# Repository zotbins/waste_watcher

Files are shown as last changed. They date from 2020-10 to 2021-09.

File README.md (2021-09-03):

# Introduction
I wanted a way to keep track of how much waste I was generating just to be more environmentally conscious. So I created this project as an automated way to help keep track of waste accumulation through fullness measurements while also taking pictures of the objects thrown away.

feature photo

# ZotBins Community Edition

This is the first step of a multi-part project of creating a smart waste ecosystem called [ZotBins](https://zotbins.github.io), which is already deployed at UCI. Currently, I am helping to further expand the concept of ZotBins where any city, business, university, classroom, or home could implement a smart waste system. This open-source version ZotBins is called  ZotBins Community Edition (ZBCE). To learn more about this initiative please visit the [ZotBins Community Edition Blog](https://zotbins.github.io/zbceblog/about/)

# Quick Start
Please follow the appropriate build guide for the waste watcher version of your choosing.
- [Waste Watcher Guide](https://github.com/zotbins/waste_watcher/blob/release-v1/guide/guide.md)
    - Measures bin fullness and collects waste images
    - Saves data and images to HTTP server
    - Syncs with NTP Client to generate UTC datetime stamps

# Contributing

Here are some following ways you can contribute:
- For this specific repository feel free to submit any issues regarding bugs. This will really help other users who may be interested in building this project and also help me create a debugging guide for the community.
- Join our [Discord](https://discord.gg/mGKVVpxTPr) server and contribute to our growing community
- Submit bugs by opening an issue on our [Github](https://github.com/zotbins). Please make sure that bugs are reported in detail and is reproducible.
- Write some documentation for a repository and we can add it to our GitHub Wiki Page
- Look for open issues on our repositories
- Suggest new features in our Discord Server
- Contribute to our crowd-sourcing projects. Occasionally, we will have certain projects that require crowd-sourced data, and would love people to help.
- Submit user feedback through feedback forms or polls in our Discord community
- Lookout for more requests for help on our Discord server

Overall, if you contribute to our project, we will feature your username on respective GitHub repositories. We really appreciate the help. For more ideas about how you can contribute to open source projects in general, feel free to take a look GitHub's [Open Source Guides](https://opensource.guide/how-to-contribute/).

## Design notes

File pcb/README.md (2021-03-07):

I also shared the project on Osh Park where you can purchase the PCB from this [link](https://oshpark.com/shared_projects/k4JhZQq0). All gerber files are also included in this folder if you wish to send to a different manufacturer or fabricate it yourself.

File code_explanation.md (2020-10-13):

# Code Explanation

First, I would really like to thank and acknowledge [Random Nerd Tutorials](https://randomnerdtutorials.com/) for giving the resources and tutorials needed to help me develop this script. They make all their tutorials free and also do their best to help out their community and give so many valuble resources for makers. Please check them out!

### Library Imports

Here we, include all the libraries we need for our script. These library enable us to use the ESP32 Camera, write to the microSD card, connect to WiFi, and determine the time using NTP. 

```c
#include "esp_camera.h"
#include "Arduino.h"
#include "FS.h"                // SD Card ESP32
#include "SD_MMC.h"            // SD Card ESP32
#include <SPI.h>               // SD Card ESP32
#include "soc/soc.h"           // Disable brownout problems
#include "soc/rtc_cntl_reg.h"  // Disable brownout problems
#include "driver/rtc_io.h"
#include <WiFi.h>
#include <NTPClient.h>
#include <WiFiUdp.h>
```

### Script Parameters and Variables

This is where we define our WiFi credentials. Make sure that you have changed those parameters so that the ESP32 CAM can properly connect to a WiFi network. This is important for determining the time. 

```c
// === wifi credentials ===
// replace with your network credentials
const char* WIFI_SSID = "CHANGE_TO_YOUR_WIFI_SSID";
const char* WIFI_PASS = "CHANGE_TO_YOUR_WIFI_PASSWORD";
```

If you have a need to change the pin assignment for the HC-SR04, feel free to change it here, but it is not reccomended because the SD card reader will be using other pins. 

```c
// === peripherals pin assignment === 
const int ultrasonicTrigPin = 13;
const int ultrasonicEchoPin = 12;  
```

This here determines the time the ESP32 CAM should go into deep sleep. In this script, it will be sleeping for 1,800 seconds or 30 minutes. Deep sleep helps reduce energy consumption when nothing is being done. You can feel free to change the time to sleep value. 

```c
// === deep sleep === 
#define uS_TO_S_FACTOR 1000000 /* conversion factor for usec to sec */
#define TIME_TO_SLEEP 1800 /* TIME ESP32 will go to sleep in sec */ 
```

Here we define all our other parameters used for determining the fullness level, figuring out where to save our fullness data, saving the datetime stamp, creating the NTP Client object, and defining all the pins for the AI THINKER ESP32 CAM model. 

```c
// === other parameters ===
const int binHeight = 100; // units: cm, used to calculate fullness
const int ultraMinRange = 2; //units: cm, min. limit of accurate HC-SR04 reading
const int ultraMaxRange = 400; //units: cm, max. limit of accurate HC-SR04 reading
const char* datalogFile = "/data.csv";

// === system variables ===
long duration; // units: microseconds, for HC-SR04
int distance; // units:cm, for HC-SR04
int fullness; //units:cm, the bin fullness
String datetimeStamp;
String path;
String dataMessage;

// Define NTP Client to get time
WiFiUDP ntpUDP;
NTPClient timeClient(ntpUDP);

// === camera pin definitions ===
#define FLASH_LED_PIN 4

//CAMERA_MODEL_AI_THINKER
#define PWDN_GPIO_NUM     32
#define RESET_GPIO_NUM    -1
#define XCLK_GPIO_NUM      0
#define SIOD_GPIO_NUM     26
#define SIOC_GPIO_NUM     27

#define Y9_GPIO_NUM       35
#define Y8_GPIO_NUM       34
#define Y7_GPIO_NUM       39
#define Y6_GPIO_NUM       36
#define Y5_GPIO_NUM       21
#define Y4_GPIO_NUM       19
#define Y3_GPIO_NUM       18
#define Y2_GPIO_NUM        5
#define VSYNC_GPIO_NUM    25
#define HREF_GPIO_NUM     23
#define PCLK_GPIO_NUM     22
```

### configInitCamera() function

Here we set up all the camera connections and also any configuration settings for the AI THINKER ESP32 CAM model.

```c
  camera_config_t config;
  config.ledc_channel = LEDC_CHANNEL_0;
  config.ledc_timer = LEDC_TIMER_0;
  config.pin_d0 = Y2_GPIO_NUM;
  config.pin_d1 = Y3_GPIO_NUM;
  config.pin_d2 = Y4_GPIO_NUM;
  config.pin_d3 = Y5_GPIO_NUM;
  config.pin_d4 = Y6_GPIO_NUM;
  config.pin_d5 = Y7_GPIO_NUM;
  config.pin_d6 = Y8_GPIO_NUM;
  config.pin_d7 = Y9_GPIO_NUM;
  config.pin_xclk = XCLK_GPIO_NUM;
  config.pin_pclk = PCLK_GPIO_NUM;
  config.pin_vsync = VSYNC_GPIO_NUM;
  config.pin_href = HREF_GPIO_NUM;
  config.pin_sscb_sda = SIOD_GPIO_NUM;
  config.pin_sscb_scl = SIOC_GPIO_NUM;
  config.pin_pwdn = PWDN_GPIO_NUM;
  config.pin_reset = RESET_GPIO_NUM;
  config.xclk_freq_hz = 20000000;
  config.pixel_format = PIXFORMAT_JPEG;
```

This is where we define the resolution of our image quality. You can change these settings to help you increase or reduce the image quality. Please read comments for more details. You can specify the jpeg quality and also the frame size such as UXGA, SGXGA, SVGA, etc. 

```c
  //=== init with high specs to pre-allocate larger buffers === 
  if(psramFound()){
    Serial.println("PSRAM found");
    config.frame_size = FRAMESIZE_UXGA;
    config.jpeg_quality = 20;  //0-63 lower number means higher quality
    config.fb_count = 2;
  } else {
    Serial.println("PSRAM not found");
    config.frame_size = FRAMESIZE_SVGA;
    config.jpeg_quality = 15;  //0-63 lower number means higher quality
    config.fb_count = 1;
  }

  // === Init Camera === 
  esp_err_t err = esp_camera_init(&config);
  if (err != ESP_OK) {
    Serial.printf("Camera init failed with error 0x%x", err);
    return;
  }
  
  // Drop down frame size for higher initial frame rate
  sensor_t * s = esp_camera_sensor_get();
  s->set_framesize(s, FRAMESIZE_UXGA);  // UXGA|SXGA|XGA|SVGA|VGA|CIF|QVGA|HQVGA|QQVGA
```

### takePhoto() function

I think the comments should cover the explanation here, please just read the comments in the function.

### fullnessRead() function

I also think the comments should cover the explanation, please read the comments int the function. 

### getDateTime() function

This really just uses the NTPClient.h library we imported before. We are using the `timeClient` object to interact with the NTP server and fetch the time. Then, if you notice we add a `-25200` offset so that we can get the datetime in Pacific Standard Time (PST). You can change this offset to reflect your timezone. The output format of the datetime stamp will look something like this `2018-04-30T16:00:13Z`. This datetime stamp will be used as the image file names when a photo is taken and also for the CSV file that will save the fullness measurements.

```c
void getDateTime() {
  timeClient.begin();
  timeClient.setTimeOffset(-25200); // offset for PST
  while(!timeClient.update()) {
    timeClient.forceUpdate();
  }
  datetimeStamp = timeClient.getFormattedDate(); //format: 2018-04-30T16:00:13Z
  datetimeStamp.replace(":","-"); // get rid of colons

  //=== end the client === 
  timeClient.end();
}
```

### writeFile() function

This is a function that writes a file to an SD card. You can see that it takes the `path` parameter, which is the path to the file you want to save in the SD card, and also the `message` parameter specifies what message you want to save in the file. This will write a new file if the file doesn't exist or overwrite an existing one if the same file already exists. We already defined a variable to write to the files `data.csv` 

```c
void writeFile(fs::FS &fs, const char * path, const char * message){
    Serial.printf("Writing file: %s\n", path);

    File file = fs.open(path, FILE_WRITE);
    if(!file){
        Serial.println("Failed to open file for writing");
        return;
    }
    if(file.print(message)){
        Serial.println("File written");
    } else {
        Serial.println("Write failed");
    }
}
```

### appendFile() function

This is very similar to the writeFile() function. However, instead of writing a new file everytime, it simply appends the message to an existing file. So you must make sure the file you are appending to already exists. We already definied a variable to append to the file `data.csv`.

```c
void appendFile(fs::FS &fs, const char * path, const char * message){
    Serial.printf("Appending to file: %s\n", path);

    File file = fs.open(path, FILE_APPEND);
    if(!file){
        Serial.println("Failed to open file for appending");
        return;
    }
    if(file.print(message)){
        Serial.println("Message appended");
    } else {
        Serial.println("Append failed");
    }
}
```

### sdSetup() function

The very first part of this function simply mounts the SD card. Next once, the card is mounted successfully, we detect the card. Most SD cards nowadays are MMC, which stands for MultiMediaCard. So if you notice I do `SD_MMC.begin("/sdcard",true)` in the if statement. This will set the SD card up in 1-bit SD bus mode as opposed to 4-bit SD bus mode. This means that the transfer rate for data will be slower, but at the same time it frees up GPIO pins 12 and 13 for us to use with the ultrasonic sensor. For more details about SD bus modes please refer to the _Additional Resources_ section below. The rest of this code simply creates the `data.csv` file if it doesn't exist already. 

```c
void sdSetup() {
  // === sd card setup === 
  // Card Mounting
  Serial.println("Starting SD Card");
  if(!SD_MMC.begin("/sdcard", true)){
    Serial.println("SD Card Mount Failed");
    return;
  }
  
  //Detect Card
  uint8_t cardType = SD_MMC.cardType();
  if(cardType == CARD_NONE){
    Serial.println("No SD Card attached");
    return;
  } 

  // If the data.txt file doesn't exist
  // Create a file on the SD card and write the data labels
  File file = SD_MMC.open(datalogFile);
  if(!file) {
    file.close();
    Serial.println("File doesn't exist");
    writeFile(SD_MMC, datalogFile, "Datetimestamp,fullness(cm)\n");
    return;
  }
  else {
    Serial.println("File already exists");  
    file.close();
  }
}
```

### setup() function

The setup function first sets up the serial monitor so that you can debug anything by opening the serial monitor. Then we setup everything we need such as the ultrasonic sensor, the SD card, it connects to WiFi, and also setups the camera. 

```c
void setup() {
  Serial.begin(115200);
  Serial.println("Setup has started...");

  // === deep sleep setup === 
  esp_sleep_enable_timer_wakeup(TIME_TO_SLEEP * uS_TO_S_FACTOR);
  Serial.println("Setup ESP32 to sleep for every " + String(TIME_TO_SLEEP) + " Seconds");

  // === ultrasonic setup ===
  pinMode(ultrasonicTrigPin, OUTPUT);
  pinMode(ultrasonicEchoPin, INPUT);

  // === sd card setup === 
  sdSetup();
  
  // === wifi setup ===
  Serial.print("Connecting to ");
  Serial.println(WIFI_SSID);
  WiFi.begin(WIFI_SSID, WIFI_PASS);
  while (WiFi.status() != WL_CONNECTED) {
    delay(500);
    Serial.print(".");
  }
  // Print local IP address and start web server
  Serial.println("");
  Serial.println("WiFi connected.");
  Serial.println("IP address: ");
  Serial.println(WiFi.localIP());
  
  // === camera setup === 
  pinMode( FLASH_LED_PIN, OUTPUT); // Setup flash
  configInitCamera(); // Setup camera 

  Serial.println("Setup finished");
  Serial.println();
  
}
```

### loop() function

This function is really the main function that helps us run all the tasks that we want to do. It takes a photo, gets the distance reading and writes everything to the SD card. Once everything is written to the SD, we go into deep sleep mode. This allows the device to reduce its energy consumption which is very useful when running on a battery source. 

```c
void loop() {
  
  // === take a photo ===
  digitalWrite(FLASH_LED_PIN,HIGH);
  takePhoto(); // will also automatically update the datetimeStamp
  digitalWrite(FLASH_LED_PIN,LOW);

  // === get distance reading ===
  fullnessRead();
  
  // === write data to sd card ===
  //update the datetime stamp 
  getDateTime();
  //create data message
  dataMessage = datetimeStamp + "," + String(fullness) + "\n"; 
  Serial.print("Writing ");
  Serial.print(dataMessage);
  Serial.println();

  // convert String to char*
  int str_len = dataMessage.length()+1;
  char charBuf[str_len];
  dataMessage.toCharArray(charBuf,str_len);

  // write to sd card
  appendFile(SD_MMC, datalogFile, charBuf);
  
  // === sleep timer ===
  Serial.println("Going to sleep now");
  delay(1000);
  Serial.flush(); 
  esp_deep_sleep_start();
  
}
```

# Resources

-   <https://randomnerdtutorials.com/esp32-ntp-client-date-time-arduino-ide/>
-   <https://randomnerdtutorials.com/telegram-esp32-cam-photo-arduino/>
-   <https://randomnerdtutorials.com/esp32-cam-take-photo-save-microsd-card/>
-   <https://techtutorialsx.com/2020/09/06/esp32-writing-file-to-sd-card/>
-   <https://www.instructables.com/Select-SD-Interface-for-ESP32/>
-   <https://randomnerdtutorials.com/esp32-cam-ai-thinker-pinout/>

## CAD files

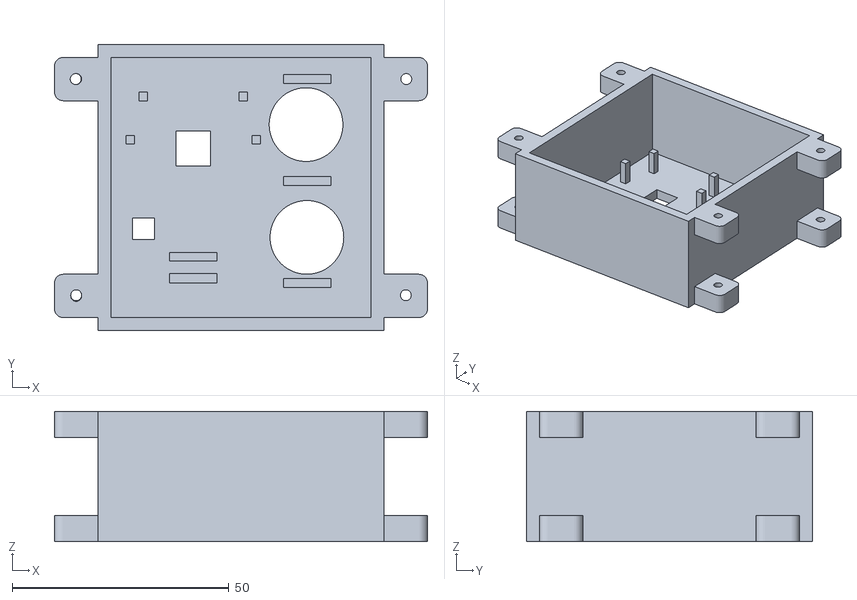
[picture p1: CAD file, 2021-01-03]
stl_files/sensor_mod_bottom_assembly.stl
86.0 x 66.0 x 30.0

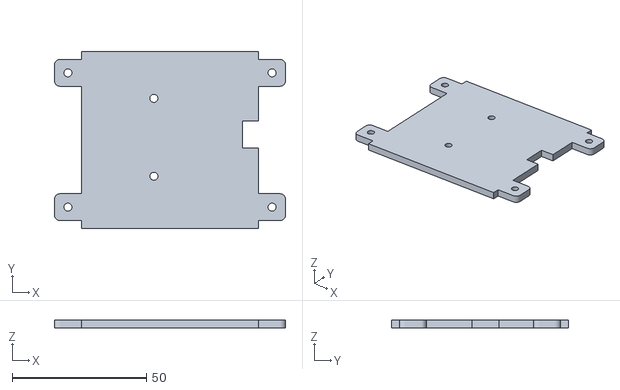
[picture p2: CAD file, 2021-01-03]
stl_files/sensor_mod_top_assembly.stl
86.0 x 66.0 x 3.00

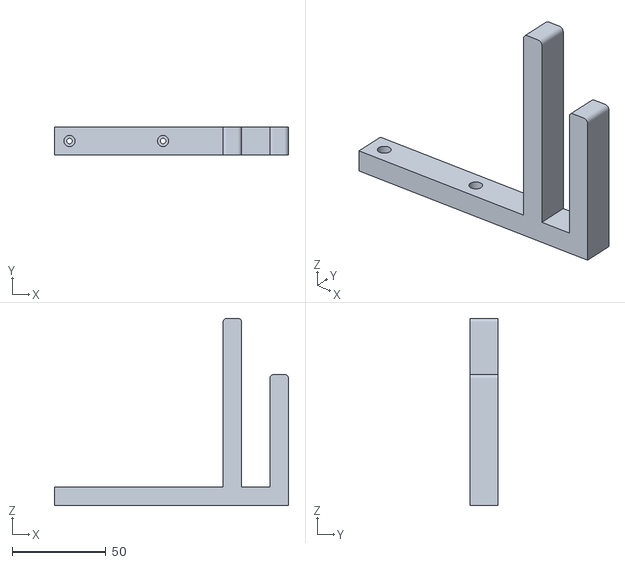
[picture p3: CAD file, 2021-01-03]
stl_files/sensor_mod_handle.stl
125.0 x 15.0 x 100.0

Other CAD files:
stl_files/sensor_mod_handle.f3d

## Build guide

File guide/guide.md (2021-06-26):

# Waste Watcher v1 Build Guide

Waste Watcher v1 is an IoT-based sensor module unit that collects bin fullness data and takes images of the trash. The main difference between v0 and v1 is the use of an HTTP server to record data instead of a SD card. This build guide will walk you through the steps of setting everything up. If you need additional help feel free to ask for help on our [Discord Server](https://discord.com/invite/mGKVVpxTPr).

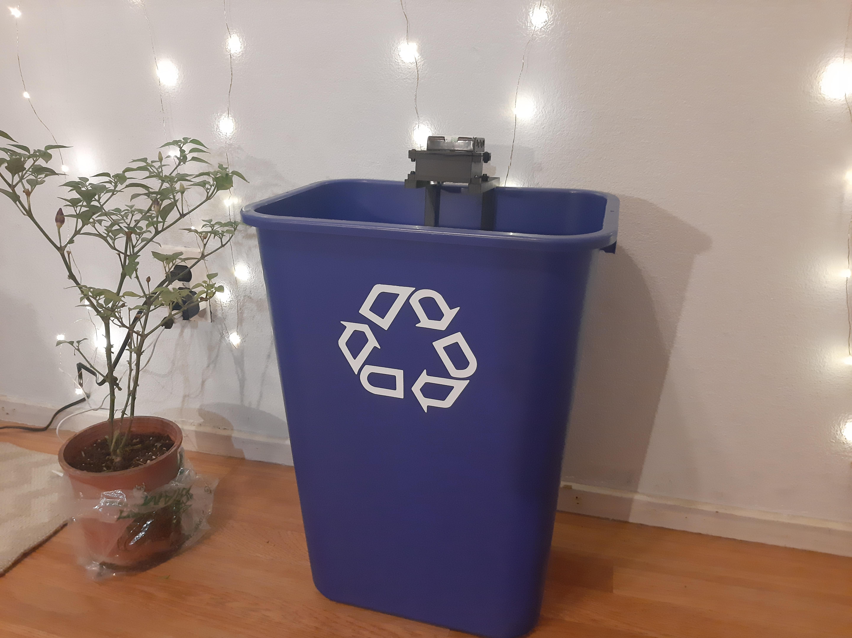
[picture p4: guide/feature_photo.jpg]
feature photo


## Features
- Sends to an HTTP server (You should set up the [ZBCE API]())
- Modular case design
- Metrics
    - bin fullness
    - waste images
- Battery Power Integration

## Steps
1. Supplies
2. Solder Components on Prototyping Board
3. Download the Arduino IDE and Add ESP32 Package
4. Select AI Thinker ESP32-CAM as Board in the Arduino IDE
5. Install the NTP Client Library
6. Preparing to Upload Code to the ESP32-CAM
7. Modify and Upload Code to the ESP32-CAM
8. Understanding the Code
9. Format and Install Your MicroSD Card
10. 3D Printing the Case
11. Start Data Logging

## 1. Supplies
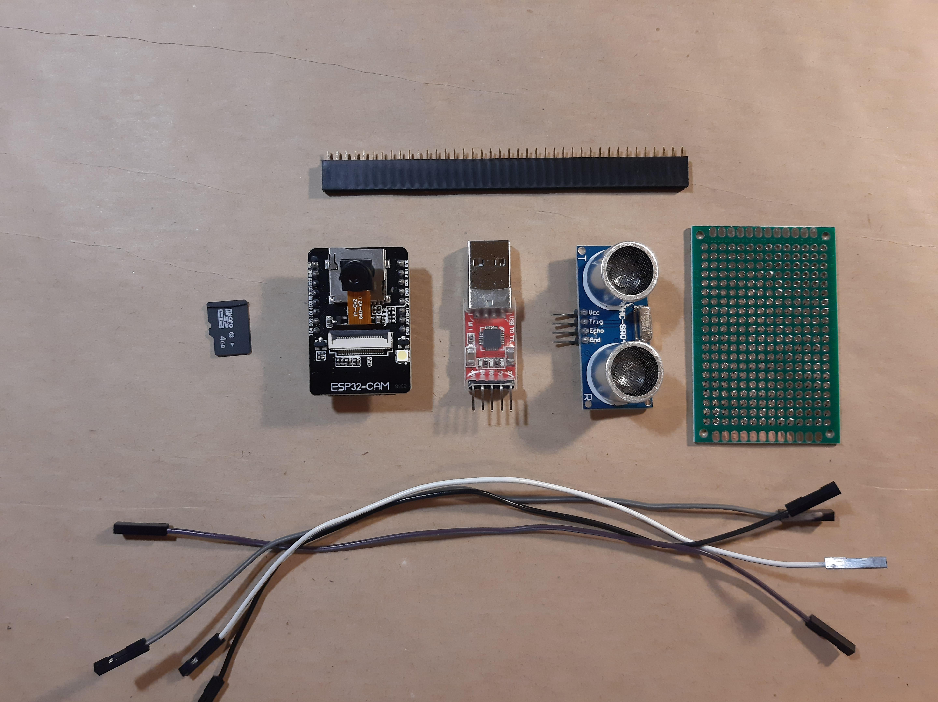
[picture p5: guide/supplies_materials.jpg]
supplies

### Materials Needed
- ESP32-CAM (~$9 per unit)
- 5V Boost Converter (~$1.5 per unit)
- HC-SR04 (~$1.60 per unit)
- Solid Wire
- Prototyping Board (~$0.80 per unit)
- Female Header Pins
- Solder
- PLA Filament
- 8 x 12mm M3 Screws*
- 8 x M3 nuts (nylon nuts recommended)

- Power Options
    - Battery
        - 3 AA Rechargeable Batteries (~$4.50 per set of 3)
        - 3 AA Battery Case (~$0.76 per unit)
    - Direct Supply
        - USB cable (stripped to expose V+ wire and GND wire)

\* 8 mm screws are sufficient, but if you want two bolt the end of the screw you need at least a 12 mm screw (see 3D Printing the Case for a better idea of where the screws will go   \

### Tools Needed
- Soldering Iron
- 3D Printer
- Wire Strippers
- Computer with Arduino IDE Installed
- FT232RL FTDI USB to TTL Serial Adapter Module (~$3.50 per unit)
- 4 Female to Female Jumper Wires
- 1 Jumper Cap or 1 Female to Female Jumper Wire  

## 2. Solder Components on Prototyping Board

1. **Use a 4cm x 3cm prototyping board.** This will be approximately the same size as the ESP32 CAM. I cut a 4cm x 6cm board in half to get that size.

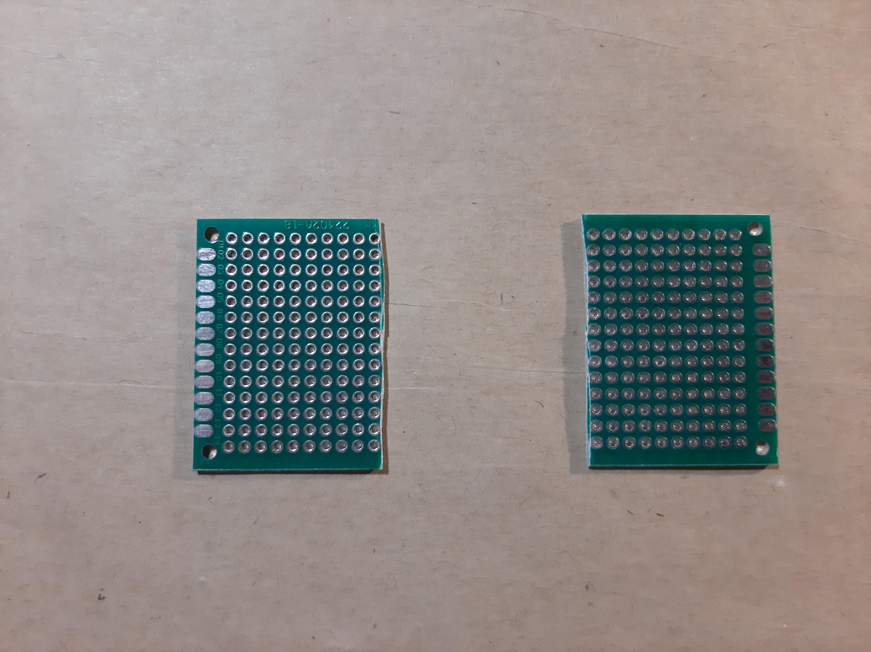
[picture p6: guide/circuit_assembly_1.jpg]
    

2. **Use two 8-pin female headers and place it on the center of board for the ESP32-CAM.** I just cut a 20 pin female header piece to get the 8-pin female headers.

    

3. **(Optional) Place a 2-pin screw terminal block connector near the top.** You can use this to conveniently plug in my battery pack of 3 AA batteries. If you don't follow this step just solder the wires from your battery pack directly into the prototyping board.
4. **Solder wires for HC-SR04 and the 5V Boost Converter.** These wires will be used to connect the components to the prototyping board.
5. **Solder Components.** Once everything is placed, just solder those components in place. See image above of my setup for reference.
6. **Plug in your ESP32 CAM into the female headers for referencing the pins.** Helps you see which pins for the female headers correspond to which pin on the ESP32 CAM.

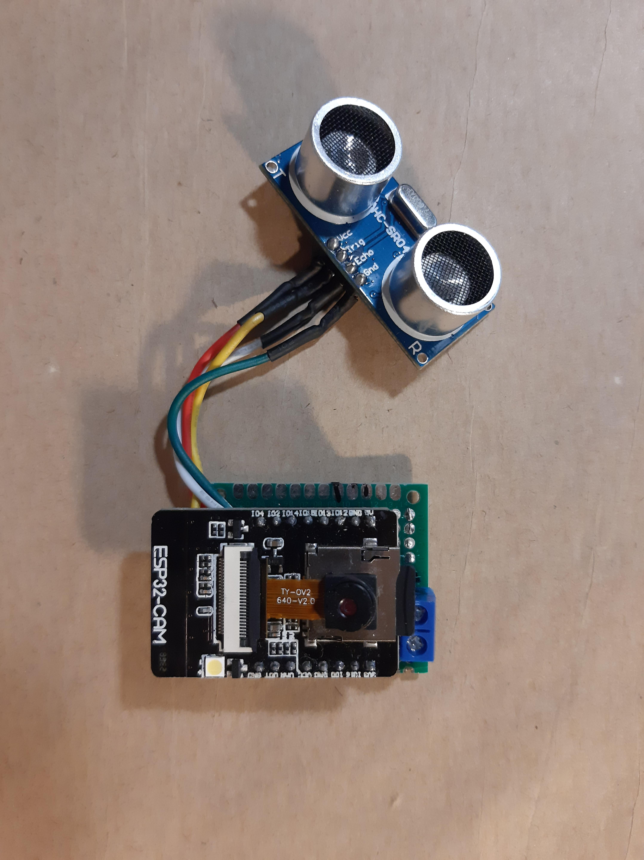
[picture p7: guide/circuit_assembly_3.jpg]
    
7. **Solder connections according to wiring diagram below.**

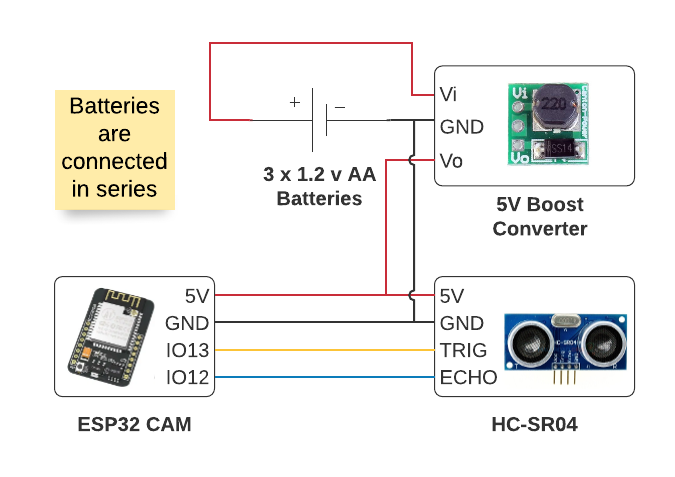
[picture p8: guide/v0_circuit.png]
    

**Circuit Explanation**

I decided to use the female headers because I wanted to reuse my ESP32-CAM for other projects as well. If you don't mind, you can directly solder everything on the ESP32-CAM.

## 3. Download the Arduino IDE and Add ESP32 Package

I was going to write my own instructions for this, but mine was really just going to be a derivative of the one on Random Nerd Tutorials. Their content is really amazing and informative so big thank you and acknowledgement to the blog creators Sara and Rui for making these resources available to the public. So instead, please follow the instructions by watching their video or by following their tutorial, **but please stop once you have the Arduino IDE and the ESP32 by Espressif Systems package installed**. I will give specific instructions for setting up the ESP32-CAM that varies from the tutorials in the next step.

Video Tutorial: [Install the ESP32 Board in Arduino IDE in less than 1 minute (Windows, Mac OS X, and Linux)](https://www.youtube.com/watch?v=mBaS3YnqDaU&feature=youtu.be)

Written Tutorial: [Installing the ESP32 Board in Arduino IDE (Mac OS X and Linux instructions)](https://randomnerdtutorials.com/installing-the-esp32-board-in-arduino-ide-mac-and-linux-instructions/)

By the end of this tutorial you should have the following:
1. An Arduino IDE
2. The correct esp32 library added in the Preferences from this source: https://dl.espressif.com/dl/package_esp32_index.json
3. esp32 library by Espressif Systems installed from **Tools > Board > Boards Manager**

## 4. Select AI Thinker ESP32-CAM as Board in the Arduino IDE

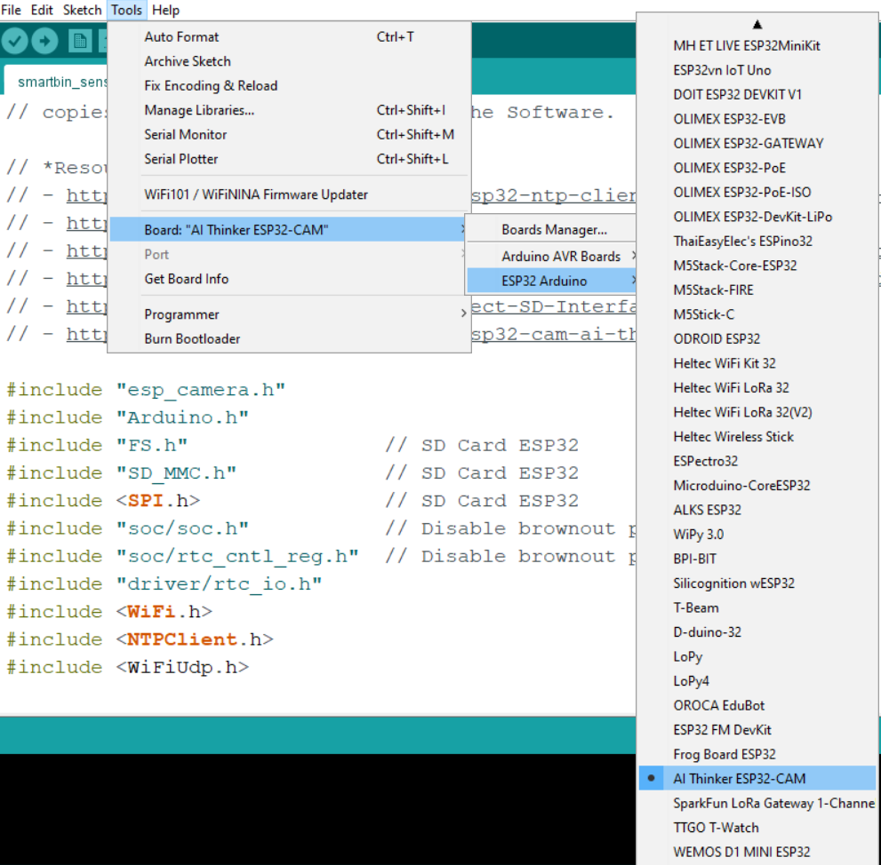
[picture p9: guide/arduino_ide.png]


Refer to the picture above for reference.

1. Near the top left of the Arduino IDE, select **Tools**
2. Then go to **Board > ESP32 Arduino > AI Thinker ESP32-CAM**
3. You might have to scroll down a bit to select **AI Thinker ESP32-CAM**

## 5. Install the NTP Client Library

We'll be using Wifi and connecting to a NTP server to keep automatically determine the date-time stamp of when the fullness data was collected and when the image was taken. The NTP server is in UTC time, you can add offsets in the code to match your timezone, I explain this in the Code Explanation section.

1. Download the NTP Client Library from GitHub here: https://github.com/taranais/NTPClient/archive/master.zip
2. Unzip the file and go into the folder. Rename the folder NTPClient-master to NTPClient

3. Move the folder to your Arduino IDE installation libraries folder. On Windows, I move the folder here: `C:\Users\REPLACE_WITH_YOUR_USERNAME\Documents\Arduino\libraries`

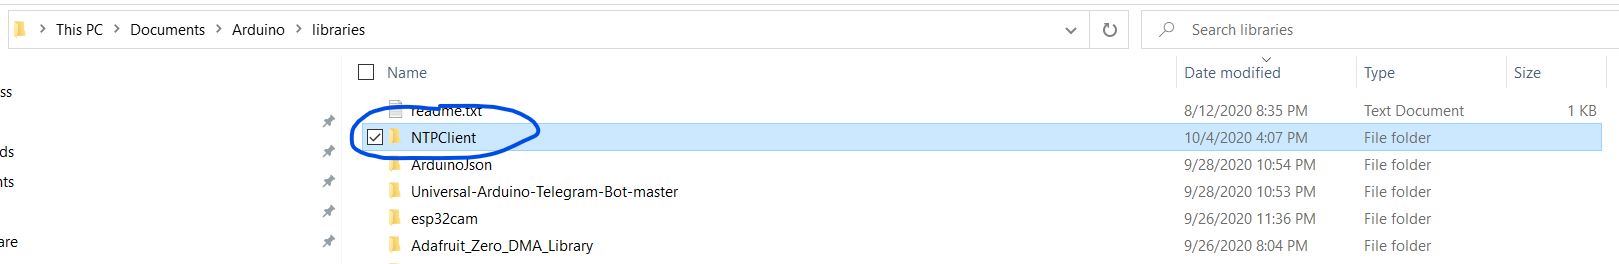
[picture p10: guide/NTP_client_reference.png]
    
NTP_client_reference.png
4. Restart the Arduino IDE

## 6. Preparing to Upload Code to the ESP32-CAM

Now that you have all the software setup. Let's start with programming the ESP32-CAM.
1. Get your FT232RL FTDI USB to TTL Serial Adapter Module (FTDI Adapter) and your Female to Female Jumper Wires
2. Connect the FTDI Adapter pins to your ESP32-CAM according to the diagram below

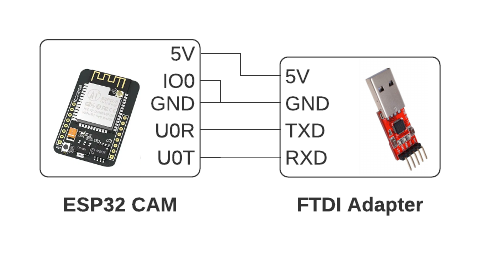
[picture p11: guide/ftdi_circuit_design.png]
    

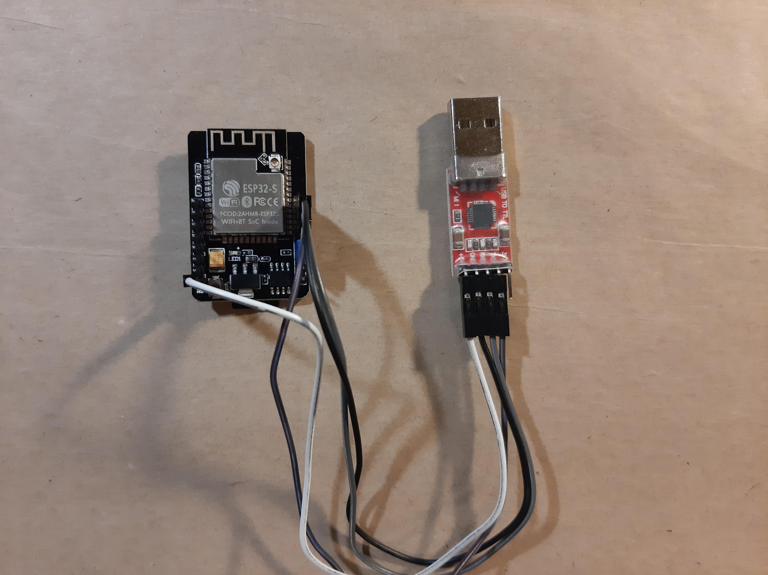
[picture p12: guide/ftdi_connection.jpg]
    

3. Plug in your FTDI Adapter USB side to the computer and make sure that your computer is able to recognize the device. If your computer does not recognize the device follow these steps:
    - Locate the required drivers here: https://ftdichip.com/drivers/d2xx-drivers/
    - Scroll down to the table and locate the driver for your operating system and follow the instructions
    - If you have a Windows machine scroll down to the table and locate the first row and click on the hyperlink labeled as Available as a setup executable
    - Once downloaded, run the executable as Administrator
4. Now, we are going put the ESP-32 CAM in programming mode
5. Make sure to connect the IO0 pin to the GND pin using either a female to female jumper wire or a jumper cap.
6. Press the reset push button on the back of the ESP32-CAM and now you should be in programming mode. This will allow you to upload your Arduino Code

## 7. Modify and Upload Code to the ESP32-CAM
Now, we're going to download the code and make some changes so that everything will work. Make sure you are still in programming mode (explained in previous step) and that your FTDI Adapter device is connected.
1. Download the *waste_watcher_code* folder from GitHub: https://github.com/zotbins/waste_watcher_code
2. Open up the code in the Arduino IDE. You should see two tabs (one called `waste_watcher_code` and the other called `config.h`). See image below for reference.

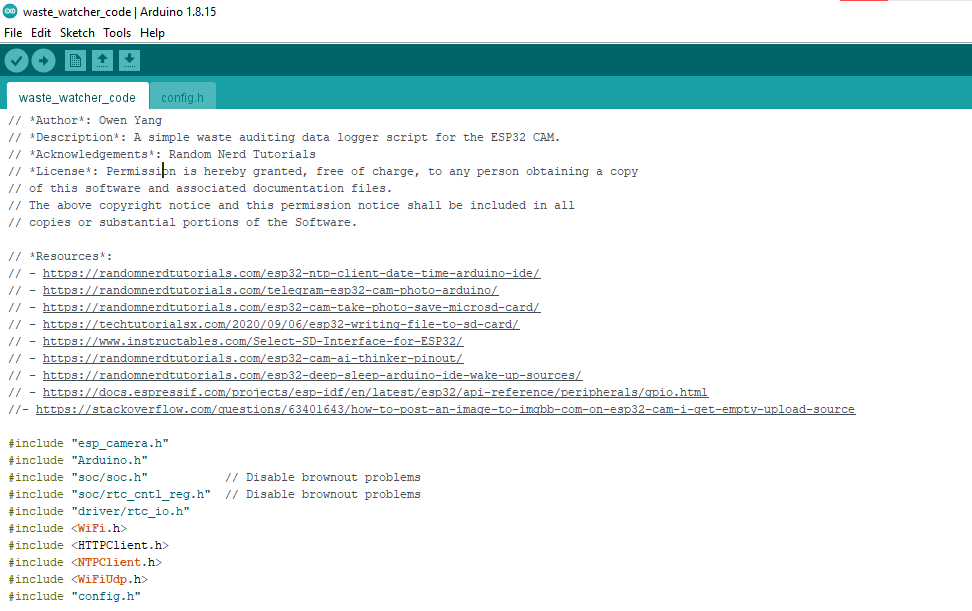
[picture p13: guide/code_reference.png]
code reference
    

3. Go to the `config.h` tab so that we can change the parameters

4. Change the following variables to match your WiFi Network and your HTTP server that is hosting the [ZBCE API](https://github.com/zotbins/zbce_api)

    ```c
    // === wifi credentials ===
    // replace with your network credentials
    const char* WIFI_SSID = "<YOUR_WIFI_SSID>";
    const char* WIFI_PASS = "<YOUR_WIFI_PASSWORD>";

    // === http request parameters ===
    String serverName = "<YOUR_SERVERNAME>"; // only the serverName, don't add http://
    ```

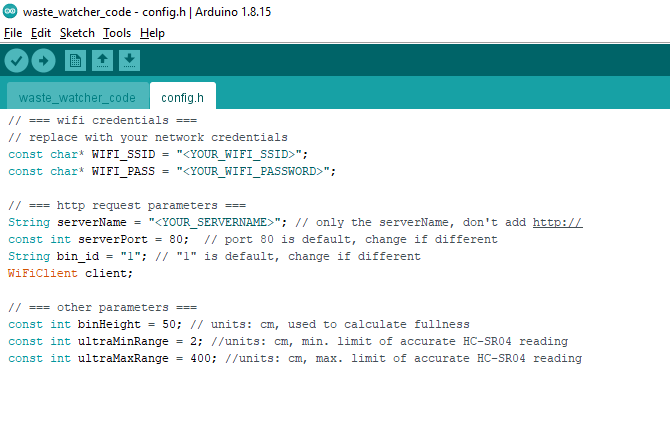
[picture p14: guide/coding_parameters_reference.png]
config reference
    

5. Measure the height of your bin and change *binHeight* value to reflect the height of your particular bin. That way the sensor module can calculate how full your bin is.
    ```c
    const int binHeight = 100; // units: cm, used to calculate fullness
    ```
3. In the Arduino IDE, make sure you select the port your FTDI Adapter device is on. **Tools > Port**

6. Now, compile and upload!

7. To test if the code works, you can open the Serial Monitor on the Arduino IDE, unplug the connection from the **IO0** pin and the **GND** pin, and reset the ESP32-CAM. This should get the ESP32-CAM out of the programming mode and will run the code we compiled and uploaded.

## 8. Understanding the Code
*Feel free to skip this section if you are not interested or just save it for later.*

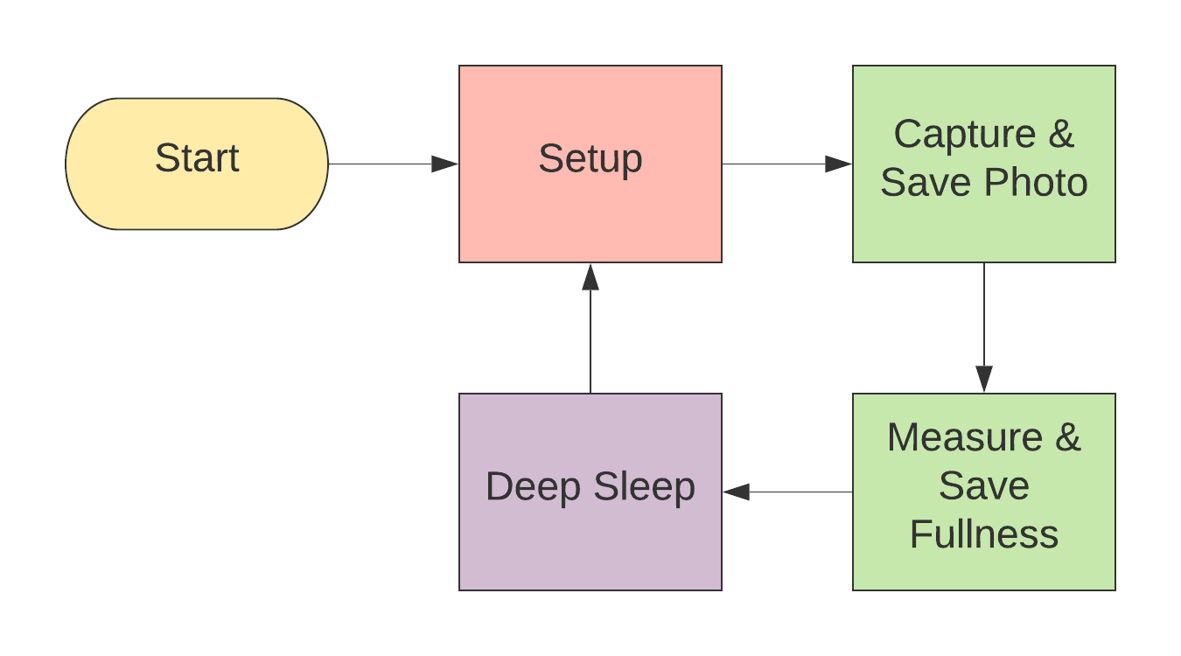
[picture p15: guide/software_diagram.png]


Above, is a quick high-level flow chart that shows the logic of the code. It is pretty simple.

However, if you want a more in-depth explanation, I made a PDF document and made it accessible on GitHub. The code explanation document will go through each block of code and also have some high-level explanation. Please see the code explanation at https://github.com/zotbins/waste_watcher/blob/main/v0/code_explanation.md

## 9. Format and Install Your MicroSD Card
1. Insert micro SD card into your computer
2. Format the SD card to a FAT32 file system
3. Once formatted, insert it into your ESP32-CAM

## 10. 3D Printing the Case

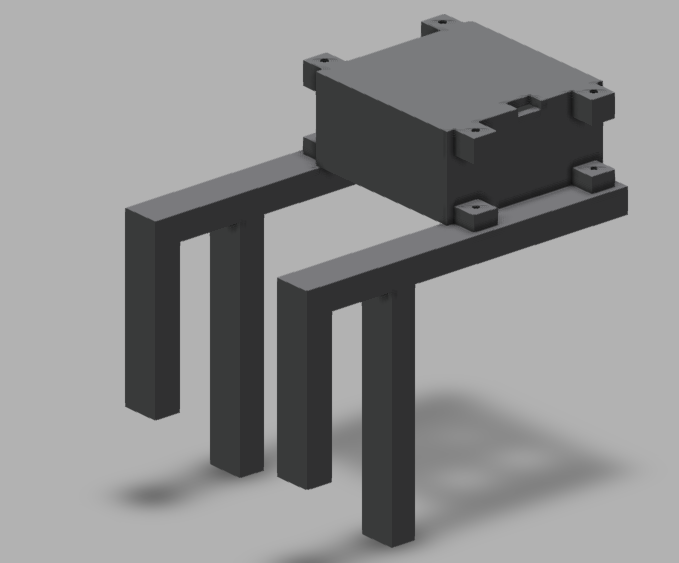
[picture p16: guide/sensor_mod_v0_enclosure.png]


1. Download the the STL files from https://github.com/zotbins/waste_watcher/tree/main/v0/stl_files
2. Infill: 10-15%
3. Supports: Everywhere
3. Print two of the *sensor_mod_handle.stl*
4. Print one of the *sensor_mod_top_assembly.stl*
5. Print one of the *sensor_mod_bottom_assembly.stl*

Currently, this design only fits on a bin with a 1cm width lip. You may have to modify the CAD file. I have included a Fusion360 file called *sensor_mod_handle v9.f3d*, in the [github repository](https://github.com/zotbins/waste_watcher), that you can modify to fit your needs. Another option is to design your own handles for your bin, I made the case pretty modular where you can create a custom attachment with M3 screws.

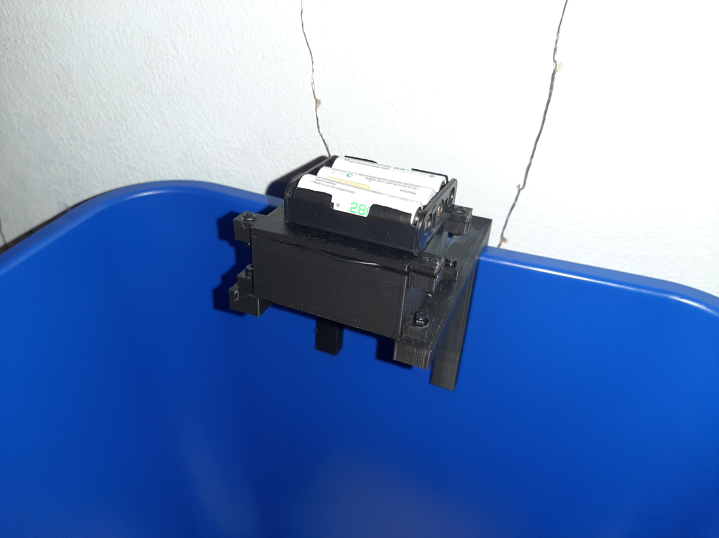
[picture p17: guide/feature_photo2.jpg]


## 11. Start Data Logging

By this step, you should have uploaded the code to the ESP32-CAM with the micro SD card inserted, have a prototyping board with the soldered circuit (HC-SR04, Female Headers, Battery Pack Holder) on it, and have a enclosure for all the components.

1. Plug in ESP32-CAM into your prototyping board
2. Put the assembled board into your 3D printed enclosure
3. Attach the enclosure onto a waste bin
4. Power your module w/ either the a 5V battery pack or a 5V USB cable
5. Congratulations! The code should start running and logging data!
6. After a period of time, you can go ahead and check the server and look at what you've thrown a way and also see the fullness trend over time. It's definitely more meaningful to collect data over a long period of time than a short period.

**Debugging**
- The flash on the camera should flash really brightly once and then go into deep sleep.
- If it keeps on flashing a couple times repeatedly every few seconds or so that means that the ESP32-CAM failed to connect to the camera module. Try resetting the board
- More debugging tips to come as I use this more and as I receive more feedback

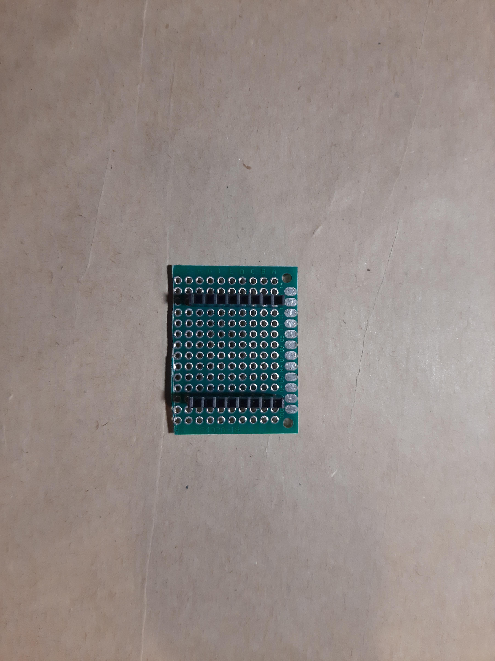
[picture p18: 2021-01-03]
guide/circuit_assembly_2.jpg

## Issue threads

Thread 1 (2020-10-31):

Low Power Sensor Module Demo Version structural enclosure

okyang, 2020-10-31:
Need to create a structural enclosure for the sensor module and upload STL file to this repo

okyang, 2020-11-15:
structural enclosure finished. see repo for the STL files.

Closed 2020-11-15.

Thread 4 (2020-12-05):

Unit tests for sensor module code

okyang, 2020-12-05:
When others build this project it would be good to have some [unit tests](https://en.wikipedia.org/wiki/Unit_testing) to see if everything on the software side is working while also checking some of the hardware. Having unit tests would be a useful feature and would be a great sanity checker.

Here are a couple possible tests to write (feel free to add more):
- ultrasonic sensor reading works
- photos can be taken
- flash turns on and off appropriately
- deep sleep works
- network is successfully connected

okyang, 2021-01-18:
Recommended software to use for unit testing:  [https://docs.platformio.org/en/latest/tutorials/core/unit_testing_blink.html]( https://docs.platformio.org/en/latest/tutorials/core/unit_testing_blink.html).

Thanks @patrickanguyen for the suggestion! 🌱

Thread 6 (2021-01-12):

ZBCE Portable Sensor Module v1 Sensor Data Collection Code

okyang, 2021-01-12:
v1 will only consist of camera and ultrasonic sensor

okyang, 2021-01-17:
v1.0 done for now. Patches can be added or new issues can be created regarding the v1 sensor data collection code.

Closed 2021-01-17.

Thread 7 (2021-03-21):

POST API Image name fix

okyang, 2021-03-21:
Once API is updated in the zbce_api repo. Update the Arduino code to use the bin id as the image name.

Closed 2021-04-13.

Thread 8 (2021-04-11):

Ultrasonic Data Mean of Medians Approach

okyang, 2021-04-11:
To ensure reliability of fullness data we want to try implementing this approach.

1. collect 9 fullness data points
2. sort the data points
3. Take the middle 5 values and take the average
4. Return that average as the fullness data

Changing this script: https://github.com/zotbins/waste_watcher/blob/main/v1/smartbin_sensor_module_v1_demo_version/smartbin_sensor_module_v1_demo_version.ino

okyang, 2021-04-11:
@DevPopat, are you interested in this?

patrickanguyen, 2021-04-13:
For the sorting, highly recommend using a iterative algorithm like insertion sort instead of a recursive one to prevent stack overflow problems

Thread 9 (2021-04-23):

Fix v0 Guide

okyang, 2021-04-23:
Update broken links and fix mistake with circuit diagram.

Closed 2021-04-28.

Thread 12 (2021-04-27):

ESP32 CAM only use flash in dim setting

okyang, 2021-04-27:

okyang, 2021-04-27:
Issue is specifically referring to this code base: [smartbin_sensor_module_v1_demo_version.ino](https://github.com/zotbins/waste_watcher/blob/main/v1/smartbin_sensor_module_v1_demo_version/smartbin_sensor_module_v1_demo_version.ino).

Still need to update the branches to follow git flow structure, will update the link above once the structure is updated, just FYI

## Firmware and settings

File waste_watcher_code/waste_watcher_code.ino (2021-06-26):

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
// *Resources*:
// - https://randomnerdtutorials.com/esp32-ntp-client-date-time-arduino-ide/
// - https://randomnerdtutorials.com/telegram-esp32-cam-photo-arduino/
// - https://randomnerdtutorials.com/esp32-cam-take-photo-save-microsd-card/
// - https://techtutorialsx.com/2020/09/06/esp32-writing-file-to-sd-card/
// - https://www.instructables.com/Select-SD-Interface-for-ESP32/
// - https://randomnerdtutorials.com/esp32-cam-ai-thinker-pinout/
// - https://randomnerdtutorials.com/esp32-deep-sleep-arduino-ide-wake-up-sources/
// - https://docs.espressif.com/projects/esp-idf/en/latest/esp32/api-reference/peripherals/gpio.html
//- https://stackoverflow.com/questions/63401643/how-to-post-an-image-to-imgbb-com-on-esp32-cam-i-get-empty-upload-source

#include "esp_camera.h"
#include "Arduino.h"
#include "soc/soc.h"           // Disable brownout problems
#include "soc/rtc_cntl_reg.h"  // Disable brownout problems
#include "driver/rtc_io.h"
#include <WiFi.h>
#include <HTTPClient.h>
#include <NTPClient.h>
#include <WiFiUdp.h>
#include "config.h"

// === peripherals pin assignment ===
const int ultrasonicTrigPin = 13;
const int ultrasonicEchoPin = 12;

// this uses the Rx pin on the ESP-32 CAM, make sure to change rtc_hold_function
// parameters below if you change this
const int nmosGate = 15;

// === deep sleep ===
#define uS_TO_S_FACTOR 1000000 //conversion factor for usec to sec
#define TIME_TO_SLEEP 1800   // TIME ESP32 will sleep for 1800 sec

// === system variables ===
long duration; // units: microseconds, for HC-SR04
int distance; // units:cm, for HC-SR04
int fullness; //units:cm, the bin fullness
String datetimeStamp;
bool debug = true;

// Define NTP Client to get time
WiFiUDP ntpUDP;
NTPClient timeClient(ntpUDP);

// === camera pin definitions ===
#define FLASH_LED_PIN 4

//CAMERA_MODEL_AI_THINKER
#define PWDN_GPIO_NUM     32
#define RESET_GPIO_NUM    -1
#define XCLK_GPIO_NUM      0
#define SIOD_GPIO_NUM     26
#define SIOC_GPIO_NUM     27

#define Y9_GPIO_NUM       35
#define Y8_GPIO_NUM       34
#define Y7_GPIO_NUM       39
#define Y6_GPIO_NUM       36
#define Y5_GPIO_NUM       21
#define Y4_GPIO_NUM       19
#define Y3_GPIO_NUM       18
#define Y2_GPIO_NUM        5
#define VSYNC_GPIO_NUM    25
#define HREF_GPIO_NUM     23
#define PCLK_GPIO_NUM     22

void configInitCamera(){
  camera_config_t config;
  config.ledc_channel = LEDC_CHANNEL_0;
  config.ledc_timer = LEDC_TIMER_0;
  config.pin_d0 = Y2_GPIO_NUM;
  config.pin_d1 = Y3_GPIO_NUM;
  config.pin_d2 = Y4_GPIO_NUM;
  config.pin_d3 = Y5_GPIO_NUM;
  config.pin_d4 = Y6_GPIO_NUM;
  config.pin_d5 = Y7_GPIO_NUM;
  config.pin_d6 = Y8_GPIO_NUM;
  config.pin_d7 = Y9_GPIO_NUM;
  config.pin_xclk = XCLK_GPIO_NUM;
  config.pin_pclk = PCLK_GPIO_NUM;
  config.pin_vsync = VSYNC_GPIO_NUM;
  config.pin_href = HREF_GPIO_NUM;
  config.pin_sscb_sda = SIOD_GPIO_NUM;
  config.pin_sscb_scl = SIOC_GPIO_NUM;
  config.pin_pwdn = PWDN_GPIO_NUM;
  config.pin_reset = RESET_GPIO_NUM;
  config.xclk_freq_hz = 20000000;
  config.pixel_format = PIXFORMAT_JPEG;

  //=== init with high specs to pre-allocate larger buffers ===
  if(psramFound()){
    if (debug) Serial.println("PSRAM found");
    config.frame_size = FRAMESIZE_UXGA;
    config.jpeg_quality = 20;  //0-63 lower number means higher quality
    config.fb_count = 2;
  } else {
    if (debug) Serial.println("PSRAM not found");
    config.frame_size = FRAMESIZE_SVGA;
    config.jpeg_quality = 15;  //0-63 lower number means higher quality
    config.fb_count = 1;
  }

  // === Init Camera ===
  esp_err_t err = esp_camera_init(&config);
  if (err != ESP_OK) {
    if (debug) Serial.printf("Camera init failed with error 0x%x", err);
    return;
  }

  // Drop down frame size for higher initial frame rate
  sensor_t * s = esp_camera_sensor_get();
  s->set_framesize(s, FRAMESIZE_UXGA);  // UXGA|SXGA|XGA|SVGA|VGA|CIF|QVGA|HQVGA|QQVGA
}

void getDateTime() {
  timeClient.begin();
  while(!timeClient.update()) {
    timeClient.forceUpdate();
  }
  datetimeStamp = timeClient.getFormattedDate(); //raw format: 2018-04-30T16:00:13Z
  datetimeStamp.replace("T"," ");
  datetimeStamp.replace("Z","");

  if (debug) Serial.println(datetimeStamp);

  //=== end the client ===
  timeClient.end();
}

String sendPhoto() {
  // === function parameters ====
  String getAll;
  String getBody;

  // === turn on flash ===
  rtc_gpio_hold_dis(GPIO_NUM_4);
  digitalWrite(FLASH_LED_PIN,HIGH);

  // === take the photo ===
  camera_fb_t * fb = NULL;
  fb = esp_camera_fb_get();

  // === turn off flash ===
  digitalWrite(FLASH_LED_PIN,LOW);
  rtc_gpio_hold_en(GPIO_NUM_4);

  // ==== retake if camera capture fails ===
  if(!fb) {
    if (debug) Serial.println("Camera capture failed");
    delay(1000);
    ESP.restart();
  }

  if (debug) Serial.println("Connecting to server: " + serverName);
  if (debug) Serial.println("Connecting to port: " + serverPort);

  if (client.connect(serverName.c_str(), serverPort)) {
    if (debug) Serial.println("Connection successful!");

    // === initialize header and tail of the file ====
    String head = "--RandomNerdTutorials\r\nContent-Disposition: form-data; name=\"file\"; filename=\"" + bin_id + ".jpg\"\r\nContent-Type: image/jpeg\r\n\r\n";
    String tail = "\r\n--RandomNerdTutorials--\r\n";

    // === image and image properties ===
    uint32_t imageLen = fb->len;
    uint32_t extraLen = head.length() + tail.length();
    uint32_t totalLen = imageLen + extraLen;

    if (debug) {
      Serial.println("POST /image HTTP/1.1");
      Serial.println("Host: " + serverName);
      Serial.println("Content-Length: " + String(totalLen));
      Serial.println("Content-Type: multipart/form-data; boundary=RandomNerdTutorials");
      Serial.println();
      Serial.print(head);
    }
    // === start post request ===
    client.println("POST /image HTTP/1.1");
    client.println("Host: " + serverName);
    client.println("Content-Length: " + String(totalLen));
    client.println("Content-Type: multipart/form-data; boundary=RandomNerdTutorials");
    client.println();
    client.print(head);

    // === write the image ===
    uint8_t *fbBuf = fb->buf;
    size_t fbLen = fb->len;
    for (size_t n=0; n<fbLen; n=n+1024) {
      if (n+1024 < fbLen) {
        client.write(fbBuf, 1024);
        fbBuf += 1024;
      }
      else if (fbLen%1024>0) {
        size_t remainder = fbLen%1024;
        client.write(fbBuf, remainder);
      }
    }
    // === end post request ===
    client.print(tail);

    esp_camera_fb_return(fb);

    int timoutTimer = 10000;
    long startTimer = millis();
    boolean state = false;

    while ((startTimer + timoutTimer) > millis()) {
      if (debug) Serial.print(".");
      delay(100);
      while (client.available()) {
        char c = client.read();
        if (c == '\n') {
          if (getAll.length()==0) { state=true; }
          getAll = "";
        }
        else if (c != '\r') { getAll += String(c); }
        if (state==true) { getBody += String(c); }
        startTimer = millis();
      }
      if (getBody.length()>0) { break; }
    }
    if (debug) Serial.println();
    client.stop();
    if (debug) Serial.println(getBody);
  }
  else {
    getBody = "Connection to " + serverName +  " failed.";
    if (debug) Serial.println(getBody);
  }
  return getBody;
}

void fullnessRead(){
  rtc_gpio_hold_dis(GPIO_NUM_15); // disable the rtc hold on nmos gate
  digitalWrite(nmosGate,HIGH);
  delayMicroseconds(500); //units: us

  // === collect ultrasonicc readings ===
  for (int i = 0; i < 5; ++i )
  {
    // clear trigger pin
    digitalWrite(ultrasonicTrigPin,LOW);
    delayMicroseconds(2); //units: us

    // Toggle trigPin HIGH then LOW
    digitalWrite(ultrasonicTrigPin,HIGH);
    delayMicroseconds(10); //units: us
    digitalWrite(ultrasonicTrigPin,LOW);

    // Reads echoPin and returns sound wave travel time
    duration = pulseIn(ultrasonicEchoPin, HIGH);
    distance = duration*0.034/2;
    if (debug) Serial.print("Raw Distance: ");
    if (debug) Serial.print(distance);
    if (debug) Serial.println();

    // Filters out out of range values
    if (distance<ultraMinRange || distance>ultraMaxRange) {
      distance = -1;
      fullness = -1;
    }
    else {
      // calculate fullness
      fullness = binHeight - distance;
      return;
    }
  }

  // Turn off signal pins
  digitalWrite(ultrasonicTrigPin,LOW);
  digitalWrite(ultrasonicTrigPin,LOW);
  digitalWrite(nmosGate,LOW);
  rtc_gpio_hold_en(GPIO_NUM_15); // enable the rtc hold on the nmos gate
}

void post_fullness() {
  if ((WiFi.status() == WL_CONNECTED)) {
    HTTPClient http;

    if (debug) Serial.println("http://"+serverName+":"+serverPort+"/fullness");
    http.begin("http://"+serverName+":"+serverPort+"/fullness");

    http.addHeader("Content-Type", "application/json");
    if (debug) Serial.println("{\"data\":[{\"datetime\":\"" + datetimeStamp  +"\",\"fullness\":"+ fullness +",\"bin_id\":"+ bin_id +"}]}");
    int httpResponseCode = http.POST("{\"data\":[{\"datetime\":\"" + datetimeStamp  +"\",\"fullness\":"+ fullness +",\"bin_id\":"+ bin_id +"}]}");

    if (debug) Serial.print("HTTP Response code: ");
    if (debug) Serial.println(httpResponseCode);
    http.end(); // Free the resources
  }
  else {
    if (debug) Serial.println("WiFi Disconnected");
  }
}

void setup() {

  if (debug) Serial.begin(115200);
  if (debug) Serial.println("Setup has started...");

  // === deep sleep setup ===
  esp_sleep_enable_timer_wakeup(TIME_TO_SLEEP * uS_TO_S_FACTOR);
  if (debug) Serial.println("Setup ESP32 to sleep for every " + String(TIME_TO_SLEEP) + " Seconds");

  // === ultrasonic setup ===
  pinMode(ultrasonicTrigPin, OUTPUT);
  pinMode(ultrasonicEchoPin, INPUT);
  pinMode(nmosGate, OUTPUT);

  // === begin wifi connection ===
  WiFi.begin(WIFI_SSID, WIFI_PASS);
  if (debug) Serial.print("Connecting to ");
  if (debug) Serial.println(WIFI_SSID);
  while (WiFi.status() != WL_CONNECTED) {
    delay(500);
    if (debug) Serial.print(".");
  }
  // Print local IP address and start web server
  if (debug) {
    Serial.println("");
    Serial.println("WiFi connected.");
    Serial.println("IP address: ");
    Serial.println(WiFi.localIP());
  }

  // === camera setup ===
  pinMode( FLASH_LED_PIN, OUTPUT); // Setup flash
  configInitCamera(); // Setup camera

  if (debug) Serial.println("Setup finished");
  if (debug) Serial.println();

  // === take a photo ===
  sendPhoto();

  // === get distance reading ===
  fullnessRead();

  //=== update the datetime stamp ===
  getDateTime();

  // === write data to HTTP Server ===
  post_fullness();

  // === sleep timer ===
  if (debug) Serial.println("Going to sleep now");
  delay(1000);
  if (debug) Serial.flush();
  esp_deep_sleep_start();

}

void loop() {

}

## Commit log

2020-10-31 added sensor module bottom assembly piece
    [sensor_mod_bottom_assembly.stl]
2020-11-01 include handle and top part for sensor module enclosure
    [sensor_mod_handle.stl, sensor_mod_top_assembly.stl]
2020-11-14 include mounting points for batter case
    [sensor_mod_handle v9.f3d, sensor_mod_handle.stl, sensor_mod_top_assembly.stl]
2021-01-02 initial commit for development
    [sensor_mod_bottom_assembly.stl, sensor_mod_handle.f3d, sensor_mod_handle.stl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]
2021-01-03 update stl files and link to stl files
    [sensor_mod_bottom_assembly.stl, sensor_mod_handle.stl, sensor_mod_top_assembly.stl]
2021-01-11 sensor mod v1 code
2021-01-17 v1 code and files updates
    [sensor_mod_bottom_assembly.stl, sensor_mod_handle.f3d, sensor_mod_handle.stl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]
2021-03-07 upload datasheets, gerber files, and README
2021-04-28 Update circuit image and update link to ftdi driver
2021-05-02 restructuring for v1
    [sensor_mod_bottom_assembly.stl, sensor_mod_handle.f3d, sensor_mod_handle.stl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]
